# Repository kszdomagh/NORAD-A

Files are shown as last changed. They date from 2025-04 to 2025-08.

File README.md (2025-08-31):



# NORAD-A

NORAD-A to minimalistyczny symulator, w którym gracz wciela się w operatora systemu radarowego w trakcie narastającego kryzysu nuklearnego. Zadaniem gracza jest monitorowanie przestrzeni powietrznej, identyfikacja potencjalnych zagrożeń i szybkie podejmowanie decyzji w oparciu o niepełne informacje. Cały interfejs gry wyświetlany jest na oscyloskopie pracującym w trybie XY, podkreślając surowy charakter rozgrywki.

# Sterowanie

## Przełączniki
SW15 - kontroluje wyświetlanie ekranu gry z mapą Stanów Zjednoczonych;

SW14 - kontroluje wyświetlanie logo kierunku MTM (https://www.mtm.agh.edu.pl/);

SW0 - reset;

## Przyciski

btnU, btnD - przyciski sterują pionowym ruchem kursora (odpowiednio UP, DOWN);

btnL, btnR - przyciski sterują poziomym ruchem kursora (odpowiednio LEFT, RIGHT);

btnC - przycisk "środkowy" wystrzeliwuje rakietę.

# Konfiguracja sprzętu
Do gry potrzebny jest oscyloskop (najlepiej analogowy) z conajmniej dwoma kanałami oraz trybem XY, dwa przetworniki cyfrowo-analogowe podłączone do portów JB oraz JC.

# Film
Film pokazujący działanie gry znajduje się pod następującym linkiem:
https://youtu.be/zArHo4Ynv9o?feature=shared

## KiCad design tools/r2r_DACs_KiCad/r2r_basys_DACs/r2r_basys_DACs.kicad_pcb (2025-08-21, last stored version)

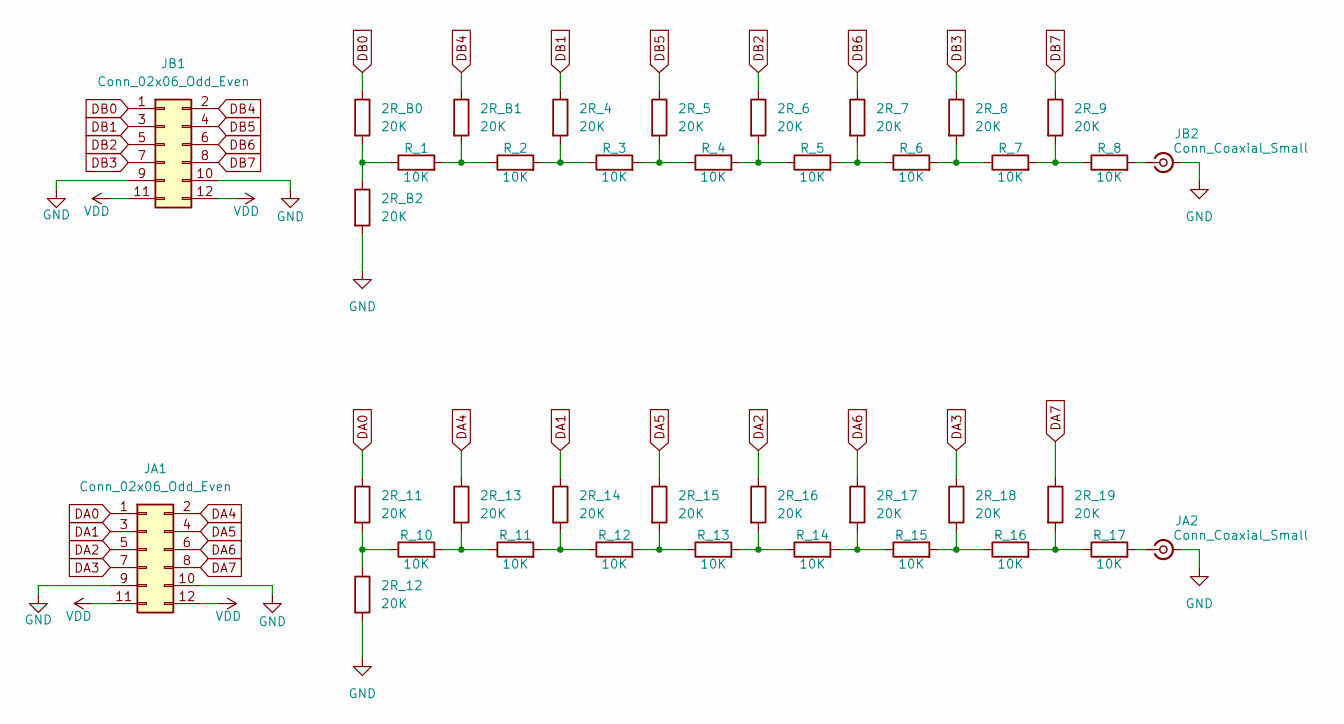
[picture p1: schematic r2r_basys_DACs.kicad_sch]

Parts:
2R_4, 2R_5, 2R_6, 2R_7, 2R_8, 2R_9, 2R_11, 2R_12, 2R_13, 2R_14, 2R_15, 2R_16, 2R_17, 2R_18, 2R_19, 2R_B0, 2R_B1, 2R_B2: 20K; R_0805_2012Metric_Pad1.20x1.40mm_HandSolder
JA1: Conn_02x06_Odd_Even; PinHeader_2x06_P2.54mm_Vertical
JA2: Conn_Coaxial_Small; SMA_Wurth_60312002114503_Vertical
JB1: Conn_02x06_Odd_Even; PinHeader_2x06_P2.54mm_Vertical
JB2: Conn_Coaxial_Small; SMA_Wurth_60312002114503_Vertical
R_1, R_2, R_3, R_4, R_5, R_6, R_7, R_8, R_10, R_11, R_12, R_13, R_14, R_15, R_16, R_17: 10K; R_0805_2012Metric_Pad1.20x1.40mm_HandSolder

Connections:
DA0: 2R_11.1, JA1.1
DA1: 2R_14.1, JA1.3
DA2: 2R_16.1, JA1.5
DA3: 2R_18.1, JA1.7
DA4: 2R_13.1, JA1.2
DA5: 2R_15.1, JA1.4
DA6: 2R_17.1, JA1.6
DA7: 2R_19.1, JA1.8
DB0: 2R_B0.1, JB1.1
DB1: 2R_4.1, JB1.3
DB2: 2R_6.1, JB1.5
DB3: 2R_8.1, JB1.7
DB4: 2R_B1.1, JB1.2
DB5: 2R_5.1, JB1.4
DB6: 2R_7.1, JB1.6
DB7: 2R_9.1, JB1.8
GND: 2R_12.2, 2R_B2.2, JA1.9, JA1.10, JA2.2 (Ext), JB1.9, JB1.10, JB2.2 (Ext)
unnamed: 2R_4.2, R_2.2, R_3.1
unnamed: 2R_5.2, R_3.2, R_4.1
unnamed: 2R_6.2, R_4.2, R_5.1
unnamed: 2R_7.2, R_5.2, R_6.1
unnamed: 2R_8.2, R_6.2, R_7.1
unnamed: 2R_9.2, R_7.2, R_8.1
unnamed: 2R_11.2, 2R_12.1, R_10.1
unnamed: 2R_13.2, R_10.2, R_11.1
unnamed: 2R_14.2, R_11.2, R_12.1
unnamed: 2R_15.2, R_12.2, R_13.1
unnamed: 2R_16.2, R_13.2, R_14.1
unnamed: 2R_17.2, R_14.2, R_15.1
unnamed: 2R_18.2, R_15.2, R_16.1
unnamed: 2R_19.2, R_16.2, R_17.1
unnamed: 2R_B0.2, 2R_B2.1, R_1.1
unnamed: 2R_B1.2, R_1.2, R_2.1
unnamed: JA2.1 (In), R_17.2
unnamed: JB2.1 (In), R_8.2
VDD: JA1.11, JA1.12, JB1.11, JB1.12

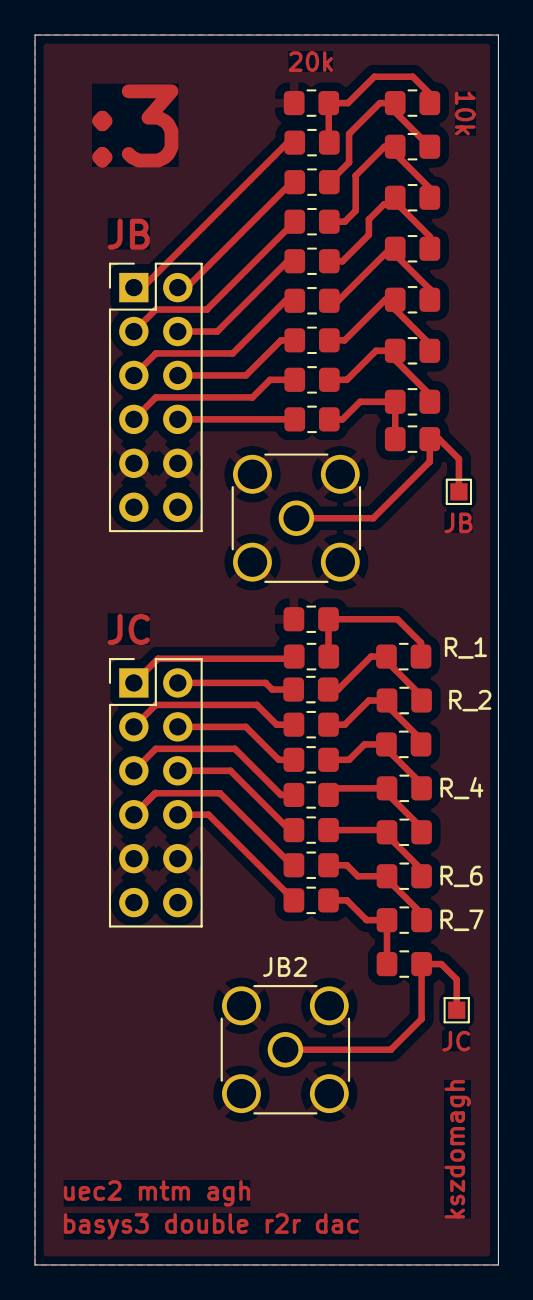
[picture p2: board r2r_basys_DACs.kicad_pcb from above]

Board: 2 copper layers, 26.8 x 71.1 mm, 38 parts (0 on the bottom side), 36 nets.

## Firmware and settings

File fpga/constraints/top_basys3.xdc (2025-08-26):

## This file is a general .xdc for the Basys3 rev B board
## To use it in a project:
## - uncomment the lines corresponding to used pins
## - rename the used ports (in each line, after get_ports) according to the top level signal names in the project

## Clock signal - NO LONGER NEEDED: TAKEN CARE OF BY CLK WIZ 0 XDC FILES
set_property PACKAGE_PIN W5 [get_ports clk_in1]
	set_property IOSTANDARD LVCMOS33 [get_ports clk_in1]
#	create_clock -add -name sys_clk_pin -period 10.00 -waveform {0 5} [get_ports clk]


## Switches
set_property PACKAGE_PIN V17 [get_ports {sw0}]
	set_property IOSTANDARD LVCMOS33 [get_ports {sw0}]
#set_property PACKAGE_PIN V16 [get_ports {sw[1]}]
	#set_property IOSTANDARD LVCMOS33 [get_ports {sw[1]}]
#set_property PACKAGE_PIN W16 [get_ports {sw[2]}]
	#set_property IOSTANDARD LVCMOS33 [get_ports {sw[2]}]
#set_property PACKAGE_PIN W17 [get_ports {sw[3]}]
	#set_property IOSTANDARD LVCMOS33 [get_ports {sw[3]}]
#set_property PACKAGE_PIN W15 [get_ports {sw[4]}]
	#set_property IOSTANDARD LVCMOS33 [get_ports {sw[4]}]
#set_property PACKAGE_PIN V15 [get_ports {sw[5]}]
	#set_property IOSTANDARD LVCMOS33 [get_ports {sw[5]}]
#set_property PACKAGE_PIN W14 [get_ports {sw[6]}]
	#set_property IOSTANDARD LVCMOS33 [get_ports {sw[6]}]
#set_property PACKAGE_PIN W13 [get_ports {sw[7]}]
	#set_property IOSTANDARD LVCMOS33 [get_ports {sw[7]}]
#set_property PACKAGE_PIN V2 [get_ports {sw[8]}]
	#set_property IOSTANDARD LVCMOS33 [get_ports {sw[8]}]
#set_property PACKAGE_PIN T3 [get_ports {sw[9]}]
	#set_property IOSTANDARD LVCMOS33 [get_ports {sw[9]}]
#set_property PACKAGE_PIN T2 [get_ports {sw[10]}]
	#set_property IOSTANDARD LVCMOS33 [get_ports {sw[10]}]
#set_property PACKAGE_PIN R3 [get_ports {sw[11]}]
	#set_property IOSTANDARD LVCMOS33 [get_ports {sw[11]}]
#set_property PACKAGE_PIN W2 [get_ports {sw12}]
	#set_property IOSTANDARD LVCMOS33 [get_ports {sw12}]
#set_property PACKAGE_PIN U1 [get_ports {sw13}]
	#set_property IOSTANDARD LVCMOS33 [get_ports {sw13}]
set_property PACKAGE_PIN T1 [get_ports {sw14}]
	set_property IOSTANDARD LVCMOS33 [get_ports {sw14}]
set_property PACKAGE_PIN R2 [get_ports sw15]
	set_property IOSTANDARD LVCMOS33 [get_ports sw15]


## LEDs
set_property PACKAGE_PIN U16 [get_ports {led0}]
	set_property IOSTANDARD LVCMOS33 [get_ports {led0}]
#set_property PACKAGE_PIN E19 [get_ports {led[1]}]
	#set_property IOSTANDARD LVCMOS33 [get_ports {led[1]}]
#set_property PACKAGE_PIN U19 [get_ports {led[2]}]
	#set_property IOSTANDARD LVCMOS33 [get_ports {led[2]}]
#set_property PACKAGE_PIN V19 [get_ports {led[3]}]
	#set_property IOSTANDARD LVCMOS33 [get_ports {led[3]}]
#set_property PACKAGE_PIN W18 [get_ports {led[4]}]
	#set_property IOSTANDARD LVCMOS33 [get_ports {led[4]}]
#set_property PACKAGE_PIN U15 [get_ports {led[5]}]
	#set_property IOSTANDARD LVCMOS33 [get_ports {led[5]}]
#set_property PACKAGE_PIN U14 [get_ports {led[6]}]
	#set_property IOSTANDARD LVCMOS33 [get_ports {led[6]}]
#set_property PACKAGE_PIN V14 [get_ports {led[7]}]
	#set_property IOSTANDARD LVCMOS33 [get_ports {led[7]}]
#set_property PACKAGE_PIN V13 [get_ports {led[8]}]
	#set_property IOSTANDARD LVCMOS33 [get_ports {led[8]}]
#set_property PACKAGE_PIN V3 [get_ports {led[9]}]
	#set_property IOSTANDARD LVCMOS33 [get_ports {led[9]}]
#set_property PACKAGE_PIN W3 [get_ports {led[10]}]
#	set_property IOSTANDARD LVCMOS33 [get_ports {led[10]}]
#set_property PACKAGE_PIN U3 [get_ports {led[11]}]
	#set_property IOSTANDARD LVCMOS33 [get_ports {led[11]}]
#set_property PACKAGE_PIN P3 [get_ports {led12}]
	#set_property IOSTANDARD LVCMOS33 [get_ports {led12}]
#set_property PACKAGE_PIN N3 [get_ports {led13}]
	#set_property IOSTANDARD LVCMOS33 [get_ports {led13}]
set_property PACKAGE_PIN P1 [get_ports {led14}]
	set_property IOSTANDARD LVCMOS33 [get_ports {led14}]
set_property PACKAGE_PIN L1 [get_ports {led15}]
	set_property IOSTANDARD LVCMOS33 [get_ports {led15}]


##7 segment display
set_property PACKAGE_PIN W7 [get_ports {seg[0]}]
	set_property IOSTANDARD LVCMOS33 [get_ports {seg[0]}]
set_property PACKAGE_PIN W6 [get_ports {seg[1]}]
	set_property IOSTANDARD LVCMOS33 [get_ports {seg[1]}]
set_property PACKAGE_PIN U8 [get_ports {seg[2]}]
	set_property IOSTANDARD LVCMOS33 [get_ports {seg[2]}]
set_property PACKAGE_PIN V8 [get_ports {seg[3]}]
	set_property IOSTANDARD LVCMOS33 [get_ports {seg[3]}]
set_property PACKAGE_PIN U5 [get_ports {seg[4]}]
	set_property IOSTANDARD LVCMOS33 [get_ports {seg[4]}]
set_property PACKAGE_PIN V5 [get_ports {seg[5]}]
	set_property IOSTANDARD LVCMOS33 [get_ports {seg[5]}]
set_property PACKAGE_PIN U7 [get_ports {seg[6]}]
	set_property IOSTANDARD LVCMOS33 [get_ports {seg[6]}]

#set_property PACKAGE_PIN V7 [get_ports dp]
	#set_property IOSTANDARD LVCMOS33 [get_ports dp]
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

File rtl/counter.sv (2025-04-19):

module counter #(
	parameter int MAXCOUNT = 255,
	parameter int COUNT_WIDTH = 8
	)(
	input logic clk,
	input logic rst,
	input logic enable,

	input logic load,
	input logic countdown,


    input logic [COUNT_WIDTH-1:0] load_number,
    output logic [COUNT_WIDTH-1:0] count_out
);


	logic [COUNT_WIDTH-1:0] count_nxt;

	always_comb begin

		 if(rst == 1)begin
			  count_nxt = 0;
        end else if(load) begin
            count_nxt = load_number;


        //      OPERATION WHEN ENABLED
        end else if (enable) begin

            if (countdown) begin
                //      COUNTING DOWN
                if (count_out == 0) begin //zeroing after overflow
                    count_nxt = MAXCOUNT;
                end else begin      //normal operation
                    count_nxt = count_out - 1;
                end

            end else begin
                //      COUNTING UP
                if (count_out == (MAXCOUNT)) begin //zeroing after overflow
                    count_nxt = 255;
                end else begin      //normal operation
                    count_nxt = count_out + 1;
                end
            end
		end else begin
		 	count_nxt = count_out;
		end
	
	end



	always_ff@(posedge clk) begin
		count_out <= count_nxt;
	end
endmodule

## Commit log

2025-04-19 y axis changes
2025-04-19 frame drawing
2025-04-19 frame changes
2025-04-19 square frame drawing optimalization for 40MEG analog osc
2025-08-12 works on hardware; minimal number of error - glitches check issue in github
    [counter.sv]
2025-08-15 added timer cluster, enemy control, added state in memory_manage and also changed back mouse control to the previous one
2025-08-15 FIX FOR VECTOR MANAGE - CHANGED ALSO SOME STUFF
    [top_rtl_tb.sv]
2025-08-16 dev tools added + fixes
    [top_rtl_tb.sv]
2025-08-20 added bases and logic for nuking
    [r2r_basys_DACs.kicad_pcb, r2r_basys_DACs.kicad_sch]
2025-08-21 r2r dac + some fixes to final game - now it semiworks
    [r2r_basys_DACs.kicad_pcb, r2r_basys_DACs.kicad_sch]
2025-08-26 missile module tested and ready to switch with current wire control unit
2025-08-30 kicad checklist
    [r2r_basys_DACs.kicad_pcb, r2r_basys_DACs.kicad_sch]
